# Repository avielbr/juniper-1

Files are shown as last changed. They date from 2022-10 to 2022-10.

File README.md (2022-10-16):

### Relevant datasheets:
- [ESP32-S2-WROOM](https://www.4project.co.il/documents/doc_664512_968259.pdf)
- [TMC6200-TA](https://www.mouser.co.il/datasheet/2/256/TMC6200_datasheet_Rev1_05-2529504.pdf) -- I also grabbed what I could from the picture in [this](https://community.simplefoc.com/t/esp32-s3-tmc6200-test-board/2418) thread discussing a board with the same MCU + gate driver.
- [NTMFS5C645NL](https://www.mouser.co.il/datasheet/2/308/NTMFS5C645NL_D-1814050.pdf) MOSFET
- [LDL1117S33R](https://www.mouser.co.il/datasheet/2/389/dm00366442-1799212.pdf) voltage regulator
- [TXU0104PWR](https://www.ti.com/lit/ds/symlink/txu0104.pdf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) level shifter

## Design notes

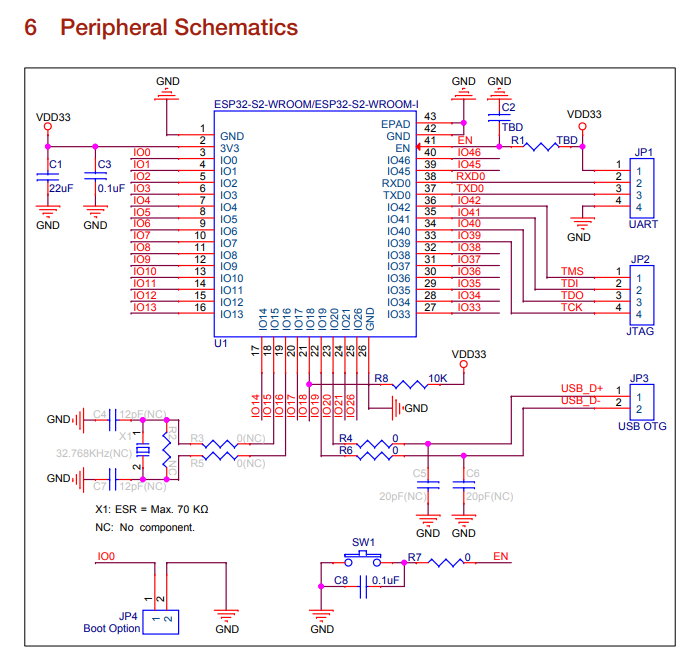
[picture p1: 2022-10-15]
kicad/parts/helper_schematics/ESP32_WROOM.png

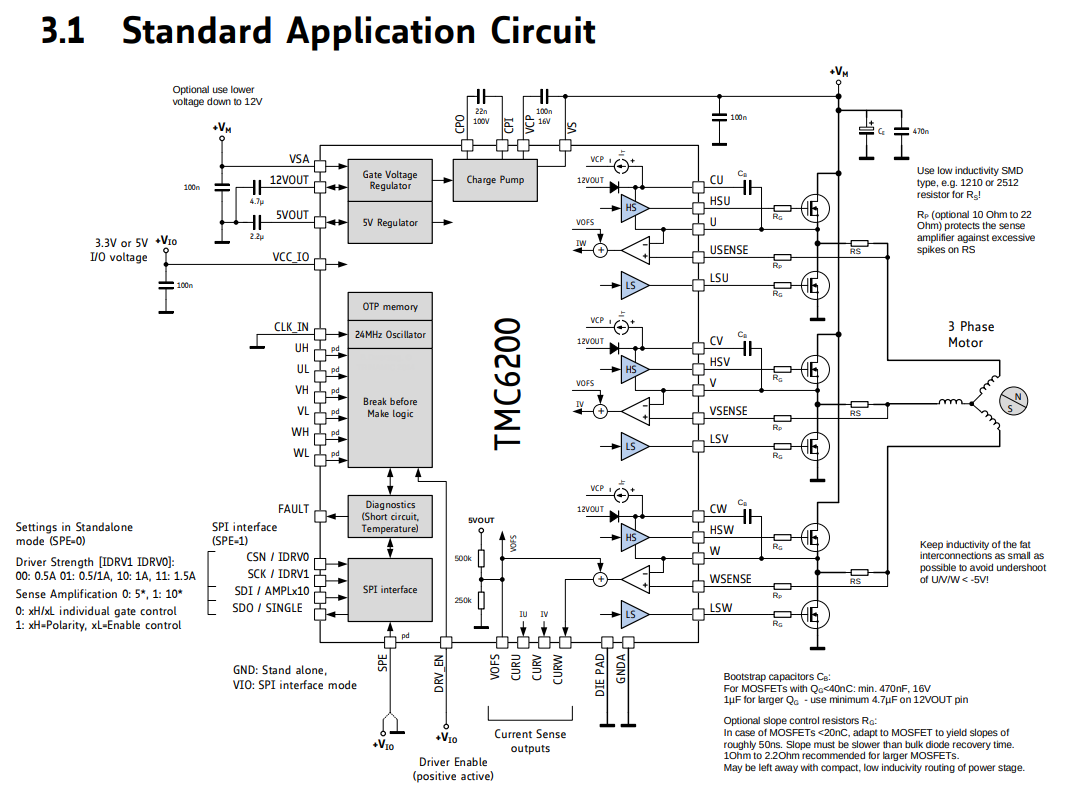
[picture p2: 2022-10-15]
kicad/parts/helper_schematics/gate_driver.png

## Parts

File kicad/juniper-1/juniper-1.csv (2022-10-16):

Source: | /home/avi/Documents/GitHub/juniper-1/kicad/juniper-1/juniper-1.kicad_sch
Date: | Sun 16 Oct 2022 02:57:48 PM IDT
Tool: | Eeschema 6.0.8-f2edbf62ab~116~ubuntu22.04.1
Generator: | /usr/share/kicad/plugins/bom_csv_grouped_by_value.py
Component Count: | 53
Individual Components:
Item | Qty | Reference(s) | Value | LibPart | Footprint | Datasheet | Arrow Part Number | Arrow Price/Stock | Availability | Description | Height | MANUFACTURER | MAXIMUM_PACKAGE_HEIGHT | MF | MP | Manufacturer_Name | Manufacturer_Part_Number | Mouser Part Number | Mouser Price/Stock | PARTREV | Package | Price | Purchase-URL | SNAPEDA_PN | STANDARD
 |  | C1 | 47uF | Device:C_Polarized | Capacitor_SMD:CP_Elec_10x10.5 | ~
 |  | C2 | 220uF | Device:C_Polarized | Capacitor_SMD:CP_Elec_10x10.5 | ~
 |  | C3 | 1500uF | Device:C_Polarized | Capacitor_SMD:CP_Elec_10x10.5 | ~
 |  | C4 | 2200uF | Device:C_Polarized | Capacitor_SMD:CP_Elec_10x10.5 | ~
 |  | C5 | 0.1uF | Device:C_Small | Capacitor_SMD:C_0402_1005Metric | ~
 |  | C6 | 22uF | Device:C_Small | Capacitor_SMD:C_0402_1005Metric | ~
 |  | C7 | 470nF | Device:C_Small | Capacitor_SMD:C_0402_1005Metric | ~
 |  | C8 | 100nF 16V | Device:C_Small | Capacitor_SMD:C_0402_1005Metric | ~
 |  | C9 | 22nF 100V | Device:C_Small | Capacitor_SMD:C_0402_1005Metric | ~
 |  | C10 | 100nF | Device:C_Small | Capacitor_SMD:C_0402_1005Metric | ~
 |  | C11 | 1uF | Device:C_Small | Capacitor_SMD:C_0402_1005Metric | ~
 |  | C12 | 470nF | Device:C_Small | Capacitor_SMD:C_0402_1005Metric | ~
 |  | C13 | 100nF | Device:C_Small | Capacitor_SMD:C_0402_1005Metric | ~
 |  | C14 | 470nF | Device:C_Small | Capacitor_SMD:C_0402_1005Metric | ~
 |  | C15 | 100nF | Device:C_Small | Capacitor_SMD:C_0402_1005Metric | ~
 |  | C16 | 0.1uF | Device:C_Small | Capacitor_SMD:C_0402_1005Metric | ~
 |  | C17 | 4.7uF | Device:C_Small | Capacitor_SMD:C_0402_1005Metric | ~
 |  | C18 | 2.2uF | Device:C_Small | Capacitor_SMD:C_0402_1005Metric | ~
 |  | C19 | 47uF | Device:C_Small | Capacitor_SMD:CP_Elec_6.3x7.7 | ~
 |  | C20 | 10uF | Device:C_Small | Capacitor_SMD:CP_Elec_6.3x7.7 | ~
 |  | J1 | BOOT_OPTION | Connector_Generic:Conn_01x02 | Connector_PinHeader_2.54mm:PinHeader_1x02_P2.54mm_Vertical | ~
 |  | J2 | UART | Connector_Generic:Conn_01x04 | Connector_PinHeader_2.54mm:PinHeader_1x04_P2.54mm_Vertical | ~
 |  | J3 | ENCODER | Connector_Generic:Conn_01x04 | Connector_PinSocket_2.54mm:PinSocket_1x04_P2.54mm_Vertical | ~
 |  | J4 | BATT_INPUT | Connector_Generic:Conn_01x02 | Connector_AMASS:AMASS_XT60-F_1x02_P7.20mm_Vertical | ~
 |  | J5 | 1714984 | 1714984:1714984 | 1714984 | https://www.phoenixcontact.com/online/portal/us/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 | 1714984 | https://www.arrow.com/en/products/1714984/phoenix-contact?region=nac |  | PCB terminal block, nominal current: 32 A, rated voltage (III/2): 1000 V, nominal cross section: 4 mm?, Number of potentials: 3, Number of rows: 1, Number of positions per row: 3, product range: MKDS 5, pitch: 9.52 mm, connection method: Screw connection with tension sleeve, mounting: Wave soldering, conductor/PCB connection direction: 0 ?, color: green, Pin layout: Linear pinning, Solder pin [P]: 5 mm, type of packaging: packed in cardboard. The article can be aligned to create different nos. of positions! | 21.7 |  |  |  |  | Phoenix Contact | 1714984 | 651-1714984 | https://www.mouser.co.uk/ProductDetail/Phoenix-Contact/1714984?qs=cyzODkzcbwBLTTPxtXl6gQ%3D%3D
 |  | Q1 | NTMFS5C645NL | NTMFS5C628NLT1G:NTMFS5C628NLT1G | TRANS_NTMFS5C628NLT1G |  |  |  |  |  |  | ON Semiconductor | 1.1 mm |  |  |  |  |  |  | 1 |  |  |  |  | Manufacturer recommendations
 |  | Q2 | NTMFS5C645NL | NTMFS5C628NLT1G:NTMFS5C628NLT1G | TRANS_NTMFS5C628NLT1G |  |  |  |  |  |  | ON Semiconductor | 1.1 mm |  |  |  |  |  |  | 1 |  |  |  |  | Manufacturer recommendations
 |  | Q3 | NTMFS5C645NL | NTMFS5C628NLT1G:NTMFS5C628NLT1G | TRANS_NTMFS5C628NLT1G |  |  |  |  |  |  | ON Semiconductor | 1.1 mm |  |  |  |  |  |  | 1 |  |  |  |  | Manufacturer recommendations
 |  | Q4 | NTMFS5C645NL | NTMFS5C628NLT1G:NTMFS5C628NLT1G | TRANS_NTMFS5C628NLT1G |  |  |  |  |  |  | ON Semiconductor | 1.1 mm |  |  |  |  |  |  | 1 |  |  |  |  | Manufacturer recommendations
 |  | Q5 | NTMFS5C645NL | NTMFS5C628NLT1G:NTMFS5C628NLT1G | TRANS_NTMFS5C628NLT1G |  |  |  |  |  |  | ON Semiconductor | 1.1 mm |  |  |  |  |  |  | 1 |  |  |  |  | Manufacturer recommendations
 |  | Q6 | NTMFS5C645NL | NTMFS5C628NLT1G:NTMFS5C628NLT1G | TRANS_NTMFS5C628NLT1G |  |  |  |  |  |  | ON Semiconductor | 1.1 mm |  |  |  |  |  |  | 1 |  |  |  |  | Manufacturer recommendations
 |  | R1 | 10K | Device:R_Small | Resistor_SMD:R_0603_1608Metric_Pad0.98x0.95mm_HandSolder | ~
 |  | R2 | 2 | Device:R_Small | Resistor_SMD:R_0603_1608Metric_Pad0.98x0.95mm_HandSolder | ~
 |  | R3 | 10K | Device:R_Small | Resistor_SMD:R_0603_1608Metric_Pad0.98x0.95mm_HandSolder | ~
 |  | R4 | 0.001 | Device:R_Small | Resistor_SMD:R_0603_1608Metric_Pad0.98x0.95mm_HandSolder | ~
 |  | R5 | 10 | Device:R_Small | Resistor_SMD:R_0603_1608Metric_Pad0.98x0.95mm_HandSolder | ~
 |  | R6 | 2 | Device:R_Small | Resistor_SMD:R_0603_1608Metric_Pad0.98x0.95mm_HandSolder | ~
 |  | R7 | 10K | Device:R_Small | Resistor_SMD:R_0603_1608Metric_Pad0.98x0.95mm_HandSolder | ~
 |  | R8 | 2 | Device:R_Small | Resistor_SMD:R_0603_1608Metric_Pad0.98x0.95mm_HandSolder | ~
 |  | R9 | 0.001 | Device:R_Small | Resistor_SMD:R_0603_1608Metric_Pad0.98x0.95mm_HandSolder | ~
 |  | R10 | 10 | Device:R_Small | Resistor_SMD:R_0603_1608Metric_Pad0.98x0.95mm_HandSolder | ~
 |  | R11 | 2 | Device:R_Small | Resistor_SMD:R_0603_1608Metric_Pad0.98x0.95mm_HandSolder | ~
 |  | R12 | 10K | Device:R_Small | Resistor_SMD:R_0603_1608Metric_Pad0.98x0.95mm_HandSolder | ~
 |  | R13 | 2 | Device:R_Small | Resistor_SMD:R_0603_1608Metric_Pad0.98x0.95mm_HandSolder | ~
 |  | R14 | 0.001 | Device:R_Small | Resistor_SMD:R_0603_1608Metric_Pad0.98x0.95mm_HandSolder | ~
 |  | R15 | 10 | Device:R_Small | Resistor_SMD:R_0603_1608Metric_Pad0.98x0.95mm_HandSolder | ~
 |  | R16 | 2 | Device:R_Small | Resistor_SMD:R_0603_1608Metric_Pad0.98x0.95mm_HandSolder | ~
 |  | R17 | 10K | Device:R_Small | Resistor_SMD:R_0603_1608Metric_Pad0.98x0.95mm_HandSolder | ~
 |  | SW1 | SW1 | Switch:SW_Push | Button_Switch_SMD:SW_Push_1P1T_NO_CK_PTS125Sx43PSMTR | ~
 |  | U1 | TMC6200-TA | TMC6200-TA:TMC6200-TA | eTQFP48_9x9_TRI
 |  | U2 | ESP32-S2-WROOM | ESP32-S2-WROOM:ESP32-S2-WROOM | XCVR_ESP32-S2-WROOM |  |  |  | In Stock | WiFi 802.11b/g/n Transceiver Module 2.4GHz Antenna Not Included, I-PEX Surface Mount |  |  |  | Espressif Systems | ESP32-S2-WROOM |  |  |  |  |  | NON STANDARD Espressif Systems | None | https://pricing.snapeda.com/search/part/ESP32-S2-WROOM/?ref=eda
 |  | U4 | TXB0102 | Logic_LevelTranslator:TXB0102DCT | Package_SO:TSSOP-8_3x3mm_P0.65mm | http://www.ti.com/lit/ds/symlink/txb0102.pdf
 |  | U5 | LDL1117S33R | LDL1117S30R:LDL1117S30R | SOT230P700X180-4N |  |  |  |  |  |  | STMicroelectronics | 1.8 mm |  |  |  |  |  |  | 7 |  |  |  | LDL1117S30R | IPC 7351B
Collated Components:
Item | Qty | Reference(s) | Value | LibPart | Footprint | Datasheet | Arrow Part Number | Arrow Price/Stock | Availability | Description | Height | MANUFACTURER | MAXIMUM_PACKAGE_HEIGHT | MF | MP | Manufacturer_Name | Manufacturer_Part_Number | Mouser Part Number | Mouser Price/Stock | PARTREV | Package | Price | Purchase-URL | SNAPEDA_PN | STANDARD
1 | 1 | C1 | 47uF | Device:C_Polarized | Capacitor_SMD:CP_Elec_10x10.5 | ~
2 | 1 | C2 | 220uF | Device:C_Polarized | Capacitor_SMD:CP_Elec_10x10.5 | ~
3 | 1 | C3 | 1500uF | Device:C_Polarized | Capacitor_SMD:CP_Elec_10x10.5 | ~
4 | 1 | C4 | 2200uF | Device:C_Polarized | Capacitor_SMD:CP_Elec_10x10.5 | ~
5 | 2 | C5, C16 | 0.1uF | Device:C_Small | Capacitor_SMD:C_0402_1005Metric | ~
6 | 1 | C6 | 22uF | Device:C_Small | Capacitor_SMD:C_0402_1005Metric | ~
7 | 3 | C7, C12, C14 | 470nF | Device:C_Small | Capacitor_SMD:C_0402_1005Metric | ~
8 | 1 | C8 | 100nF 16V | Device:C_Small | Capacitor_SMD:C_0402_1005Metric | ~
9 | 1 | C9 | 22nF 100V | Device:C_Small | Capacitor_SMD:C_0402_1005Metric | ~
10 | 3 | C10, C13, C15 | 100nF | Device:C_Small | Capacitor_SMD:C_0402_1005Metric | ~
11 | 1 | C11 | 1uF | Device:C_Small | Capacitor_SMD:C_0402_1005Metric | ~
12 | 1 | C17 | 4.7uF | Device:C_Small | Capacitor_SMD:C_0402_1005Metric | ~
13 | 1 | C18 | 2.2uF | Device:C_Small | Capacitor_SMD:C_0402_1005Metric | ~
14 | 1 | C19 | 47uF | Device:C_Small | Capacitor_SMD:CP_Elec_6.3x7.7 | ~
15 | 1 | C20 | 10uF | Device:C_Small | Capacitor_SMD:CP_Elec_6.3x7.7 | ~
16 | 1 | J1 | BOOT_OPTION | Connector_Generic:Conn_01x02 | Connector_PinHeader_2.54mm:PinHeader_1x02_P2.54mm_Vertical | ~
17 | 1 | J2 | UART | Connector_Generic:Conn_01x04 | Connector_PinHeader_2.54mm:PinHeader_1x04_P2.54mm_Vertical | ~
18 | 1 | J3 | ENCODER | Connector_Generic:Conn_01x04 | Connector_PinSocket_2.54mm:PinSocket_1x04_P2.54mm_Vertical | ~
19 | 1 | J4 | BATT_INPUT | Connector_Generic:Conn_01x02 | Connector_AMASS:AMASS_XT60-F_1x02_P7.20mm_Vertical | ~
20 | 1 | J5 | 1714984 | 1714984:1714984 | 1714984 | https://www.phoenixcontact.com/online/portal/us/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 | 1714984 | https://www.arrow.com/en/products/1714984/phoenix-contact?region=nac |  | PCB terminal block, nominal current: 32 A, rated voltage (III/2): 1000 V, nominal cross section: 4 mm?, Number of potentials: 3, Number of rows: 1, Number of positions per row: 3, product range: MKDS 5, pitch: 9.52 mm, connection method: Screw connection with tension sleeve, mounting: Wave soldering, conductor/PCB connection direction: 0 ?, color: green, Pin layout: Linear pinning, Solder pin [P]: 5 mm, type of packaging: packed in cardboard. The article can be aligned to create different nos. of positions! | 21.7 |  |  |  |  | Phoenix Contact | 1714984 | 651-1714984 | https://www.mouser.co.uk/ProductDetail/Phoenix-Contact/1714984?qs=cyzODkzcbwBLTTPxtXl6gQ%3D%3D
21 | 6 | Q1, Q2, Q3, Q4, Q5, Q6 | NTMFS5C645NL | NTMFS5C628NLT1G:NTMFS5C628NLT1G | TRANS_NTMFS5C628NLT1G |  |  |  |  |  |  | ON Semiconductor | 1.1 mm |  |  |  |  |  |  | 1 |  |  |  |  | Manufacturer recommendations
22 | 5 | R1, R3, R7, R12, R17 | 10K | Device:R_Small | Resistor_SMD:R_0603_1608Metric_Pad0.98x0.95mm_HandSolder | ~
23 | 6 | R2, R6, R8, R11, R13, R16 | 2 | Device:R_Small | Resistor_SMD:R_0603_1608Metric_Pad0.98x0.95mm_HandSolder | ~
24 | 3 | R4, R9, R14 | 0.001 | Device:R_Small | Resistor_SMD:R_0603_1608Metric_Pad0.98x0.95mm_HandSolder | ~
25 | 3 | R5, R10, R15 | 10 | Device:R_Small | Resistor_SMD:R_0603_1608Metric_Pad0.98x0.95mm_HandSolder | ~
26 | 1 | SW1 | SW1 | Switch:SW_Push | Button_Switch_SMD:SW_Push_1P1T_NO_CK_PTS125Sx43PSMTR | ~
27 | 1 | U1 | TMC6200-TA | TMC6200-TA:TMC6200-TA | eTQFP48_9x9_TRI
28 | 1 | U2 | ESP32-S2-WROOM | ESP32-S2-WROOM:ESP32-S2-WROOM | XCVR_ESP32-S2-WROOM |  |  |  | In Stock | WiFi 802.11b/g/n Transceiver Module 2.4GHz Antenna Not Included, I-PEX Surface Mount |  |  |  | Espressif Systems | ESP32-S2-WROOM |  |  |  |  |  | NON STANDARD Espressif Systems | None | https://pricing.snapeda.com/search/part/ESP32-S2-WROOM/?ref=eda
29 | 1 | U4 | TXB0102 | Logic_LevelTranslator:TXB0102DCT | Package_SO:TSSOP-8_3x3mm_P0.65mm | http://www.ti.com/lit/ds/symlink/txb0102.pdf
30 | 1 | U5 | LDL1117S33R | LDL1117S30R:LDL1117S30R | SOT230P700X180-4N |  |  |  |  |  |  | STMicroelectronics | 1.8 mm |  |  |  |  |  |  | 7 |  |  |  | LDL1117S30R | IPC 7351B

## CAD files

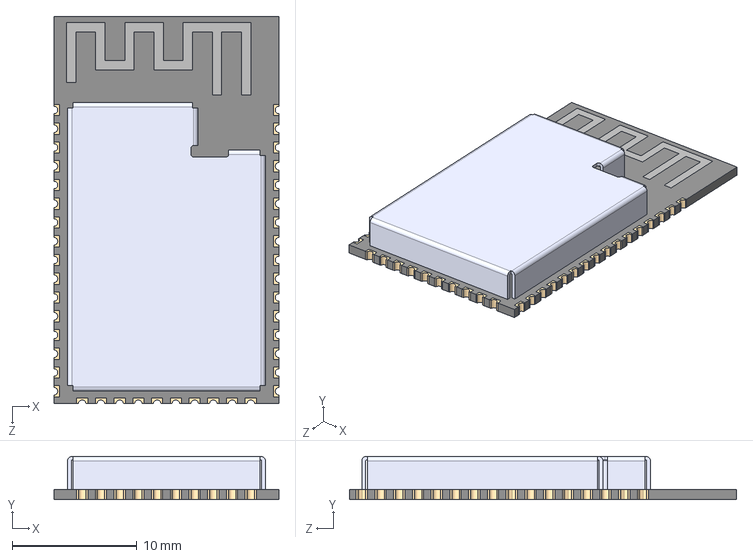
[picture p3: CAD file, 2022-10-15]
kicad/parts/ESP32-S2-WROOM/ESP32-S2-WROOM.step
18.0 x 3.45 x 31.0 mm

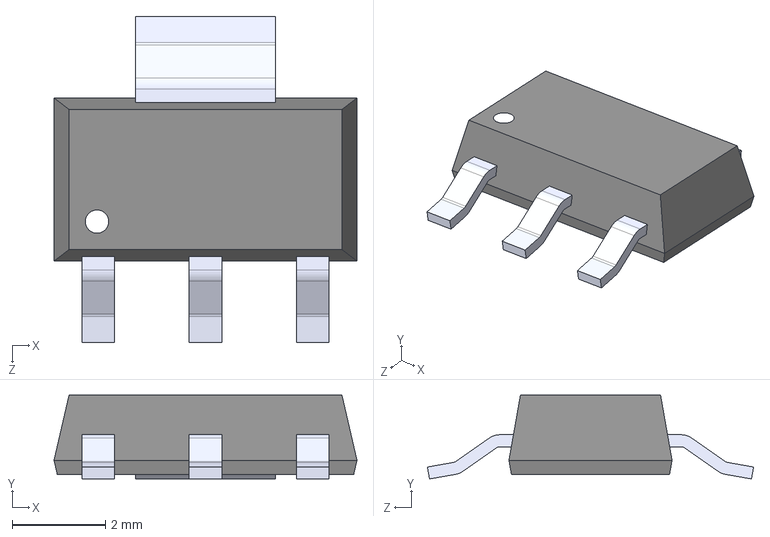
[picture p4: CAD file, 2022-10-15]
kicad/parts/LDL1117S30R/LDL1117S30R.step
6.50 x 1.80 x 7.00 mm

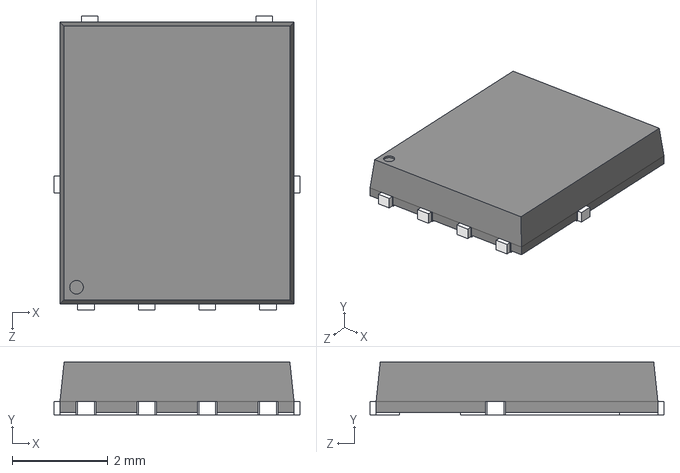
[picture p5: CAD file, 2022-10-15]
kicad/parts/NTMFS5C628NLT1G/NTMFS5C628NLT1G.step
5.15 x 1.10 x 6.15 mm

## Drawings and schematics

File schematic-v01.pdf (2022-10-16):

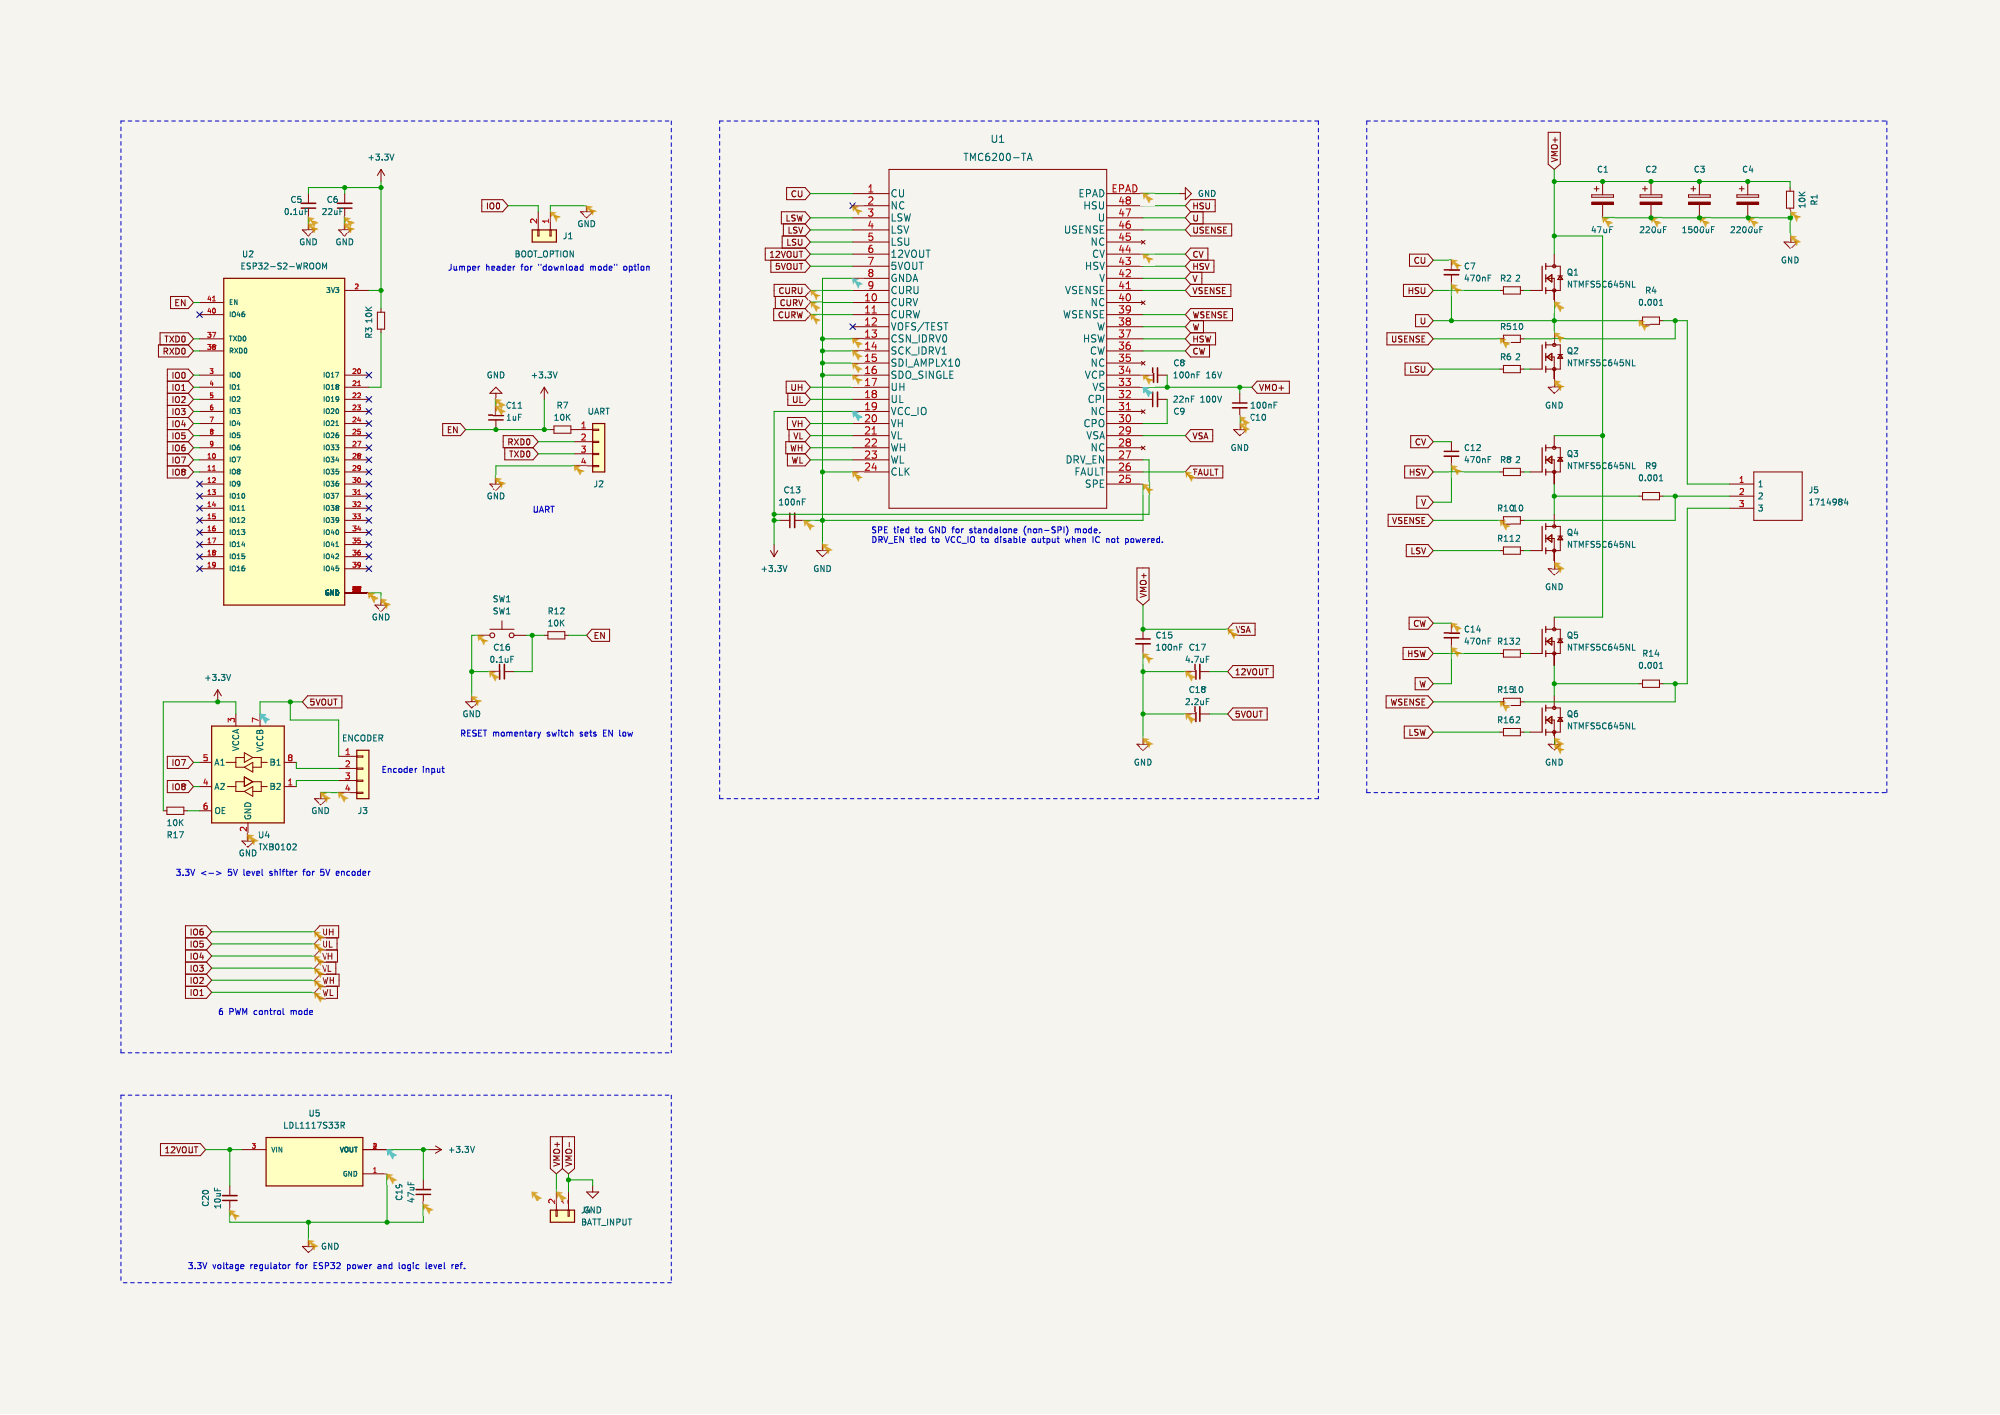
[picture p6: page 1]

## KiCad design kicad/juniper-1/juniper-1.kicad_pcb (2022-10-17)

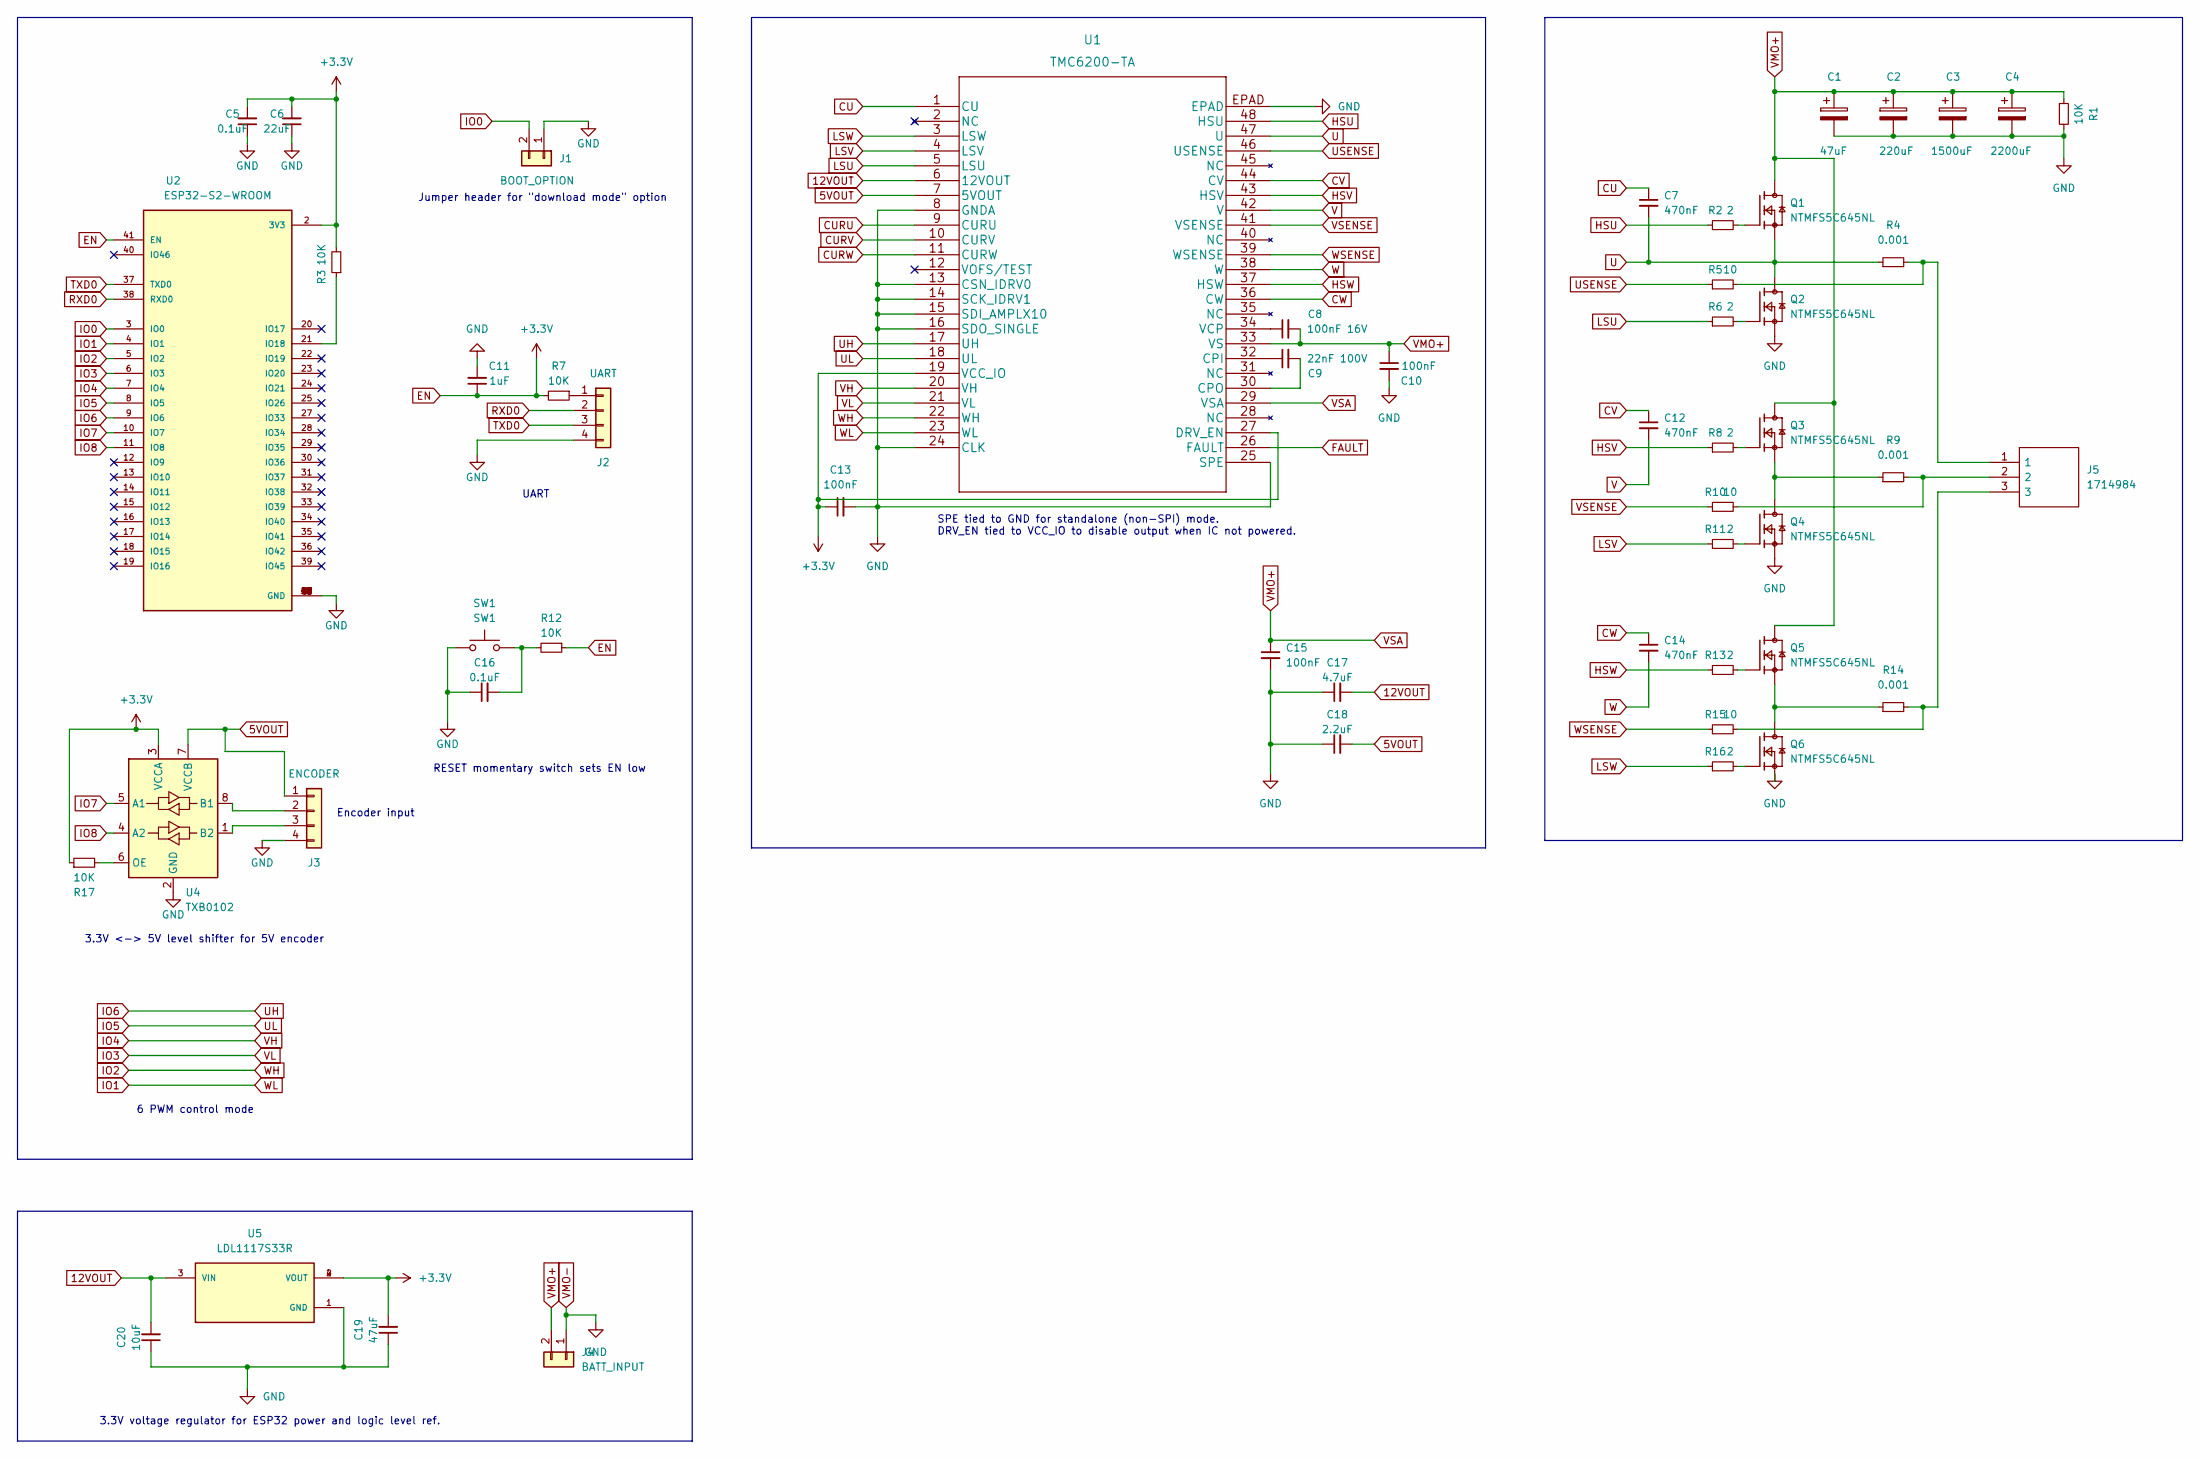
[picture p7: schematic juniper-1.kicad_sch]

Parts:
C1: 47uF; CP_Elec_10x10.5
C2: 220uF; CP_Elec_10x10.5
C3: 1500uF; CP_Elec_10x10.5
C4: 2200uF; CP_Elec_10x10.5
C5, C16: 0.1uF; C_0402_1005Metric
C6: 22uF; C_0402_1005Metric
C7, C12, C14: 470nF; C_0402_1005Metric
C8: 100nF 16V; C_0402_1005Metric
C9: 22nF 100V; C_0402_1005Metric
C10, C13, C15: 100nF; C_0402_1005Metric
C11: 1uF; C_0402_1005Metric
C17: 4.7uF; C_0402_1005Metric
C18: 2.2uF; C_0402_1005Metric
C19: 47uF; CP_Elec_6.3x7.7
C20: 10uF; CP_Elec_6.3x7.7
J1: BOOT_OPTION; PinHeader_1x02_P2.54mm_Vertical
J2: UART; PinHeader_1x04_P2.54mm_Vertical
J3: ENCODER; PinSocket_1x04_P2.54mm_Vertical
J4: BATT_INPUT; AMASS_XT60-F_1x02_P7.20mm_Vertical
J5: 1714984; Manufacturer_Part_Number 1714984; Mouser Part Number 651-1714984
Q1, Q2, Q3, Q4, Q5, Q6: NTMFS5C645NL; TRANS_NTMFS5C628NLT1G; PARTREV 1
R1, R3, R7, R12, R17: 10K; R_0603_1608Metric_Pad0.98x0.95mm_HandSolder
R2, R6, R8, R11, R13, R16: 2; R_0603_1608Metric_Pad0.98x0.95mm_HandSolder
R4, R9, R14: 0.001; R_0603_1608Metric_Pad0.98x0.95mm_HandSolder
R5, R10, R15: 10; R_0603_1608Metric_Pad0.98x0.95mm_HandSolder
SW1: SW1; SW_Push_1P1T_NO_CK_PTS125Sx43PSMTR
U1: TMC6200-TA
U2: ESP32-S2-WROOM; XCVR_ESP32-S2-WROOM
U4: TXB0102; TSSOP-8_3x3mm_P0.65mm
U5: LDL1117S33R; SOT230P700X180-4N; PARTREV 7

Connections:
5VOUT: C18.2, J3.1, U1.7 (5VOUT), U4.7 (VCCB)
12VOUT: C17.2, C20.2, U1.6 (12VOUT), U5.3 (VIN)
CU: C7.1, U1.1 (CU)
CURU: U1.9 (CURU)
CURV: U1.10 (CURV)
CURW: U1.11 (CURW)
CV: C12.1, U1.44 (CV)
CW: C14.1, U1.36 (CW)
EN: C5.2, C6.2, C11.1, C13.1, C19.2, R3.2, R7.2, R12.1, R17.1, U1.19 (VCC_IO), U1.27 (DRV_EN), U2.2 (3V3), U2.41 (EN), U4.3 (VCCA), U5.2 (VOUT), U5.4 (VOUT)
FAULT: U1.26 (FAULT)
HSU: R2.1, U1.48 (HSU)
HSV: R8.1, U1.43 (HSV)
HSW: R13.1, U1.37 (HSW)
IO0: J1.2, U2.3 (IO0)
IO1: U1.23 (WL), U2.4 (IO1)
IO2: U1.22 (WH), U2.5 (IO2)
IO3: U1.21 (VL), U2.6 (IO3)
IO4: U1.20 (VH), U2.7 (IO4)
IO5: U1.18 (UL), U2.8 (IO5)
IO6: U1.17 (UH), U2.9 (IO6)
IO7: U2.10 (IO7), U4.5 (A1)
IO8: U2.11 (IO8), U4.4 (A2)
LSU: R6.1, U1.5 (LSU)
LSV: R11.1, U1.4 (LSV)
LSW: R16.1, U1.3 (LSW)
unnamed: C8.1, U1.34 (VCP)
unnamed: C9.1, U1.32 (CPI)
unnamed: C9.2, U1.30 (CPO)
unnamed: C16.2, R12.2, SW1.2
unnamed: J2.1, R7.1
unnamed: J3.2, U4.8 (B1)
unnamed: J3.3, U4.1 (B2)
unnamed: Q1.4, R2.2
unnamed: Q2.4, R6.2
unnamed: Q3.1, Q3.2, Q3.3, Q4.5, R9.1
unnamed: Q3.4, R8.2
unnamed: Q4.4, R11.2
unnamed: Q5.1, Q5.2, Q5.3, Q6.5, R14.1
unnamed: Q5.4, R13.2
unnamed: Q6.4, R16.2
unnamed: J5.1, R4.2, R5.2
unnamed: J5.2, R9.2, R10.2
unnamed: J5.3, R14.2, R15.2
unnamed: R3.1, U2.21 (IO18)
unnamed: R17.2, U4.6 (OE)
RXD0: J2.2, U2.38 (RXD0)
TXD0: J2.3, U2.37 (TXD0)
U: C7.2, Q1.1, Q1.2, Q1.3, Q2.5, R4.1, U1.47 (U)
USENSE: R5.1, U1.46 (USENSE)
V: C12.2, U1.42 (V)
VMO+: C1.1, C2.1, C3.1, C4.1, C8.2, C10.1, C15.1, J4.2, Q1.5, Q3.5, Q5.5, R1.1, U1.29 (VSA), U1.33 (VS)
VMO-: C1.2, C2.2, C3.2, C4.2, C5.1, C6.1, C10.2, C11.2, C13.2, C15.2, C16.1, C17.1, C18.1, C19.1, C20.1, J1.1, J2.4, J3.4, J4.1, Q2.1, Q2.2, Q2.3, Q4.1, Q4.2, Q4.3, Q6.1, Q6.2, Q6.3, R1.2, SW1.1, U1.8 (GNDA), U1.13 (CSN_IDRV0), U1.14 (SCK_IDRV1), U1.15 (SDI_AMPLX10), U1.16 (SDO_SINGLE), U1.24 (CLK), U1.25 (SPE), U1.EPAD, U2.1 (GND), U2.26 (GND), U2.42 (GND), U2.43 (GND), U2.44 (GND), U2.45 (GND), U2.46 (GND), U2.47 (GND), U2.48 (GND), U2.49 (GND), U2.50 (GND), U2.51 (GND), U4.2 (GND), U5.1 (GND)
VSENSE: R10.1, U1.41 (VSENSE)
W: C14.2, U1.38 (W)
WSENSE: R15.1, U1.39 (WSENSE)

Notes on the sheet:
UART
6 PWM control mode
3.3V voltage regulator for ESP32 power and logic level ref.
Jumper header for "download mode" option
RESET momentary switch sets EN low
3.3V <-> 5V level shifter for 5V encoder
SPE tied to GND for standalone (non-SPI) mode. DRV_EN tied to VCC_IO to disable output when IC not powered.
Encoder input

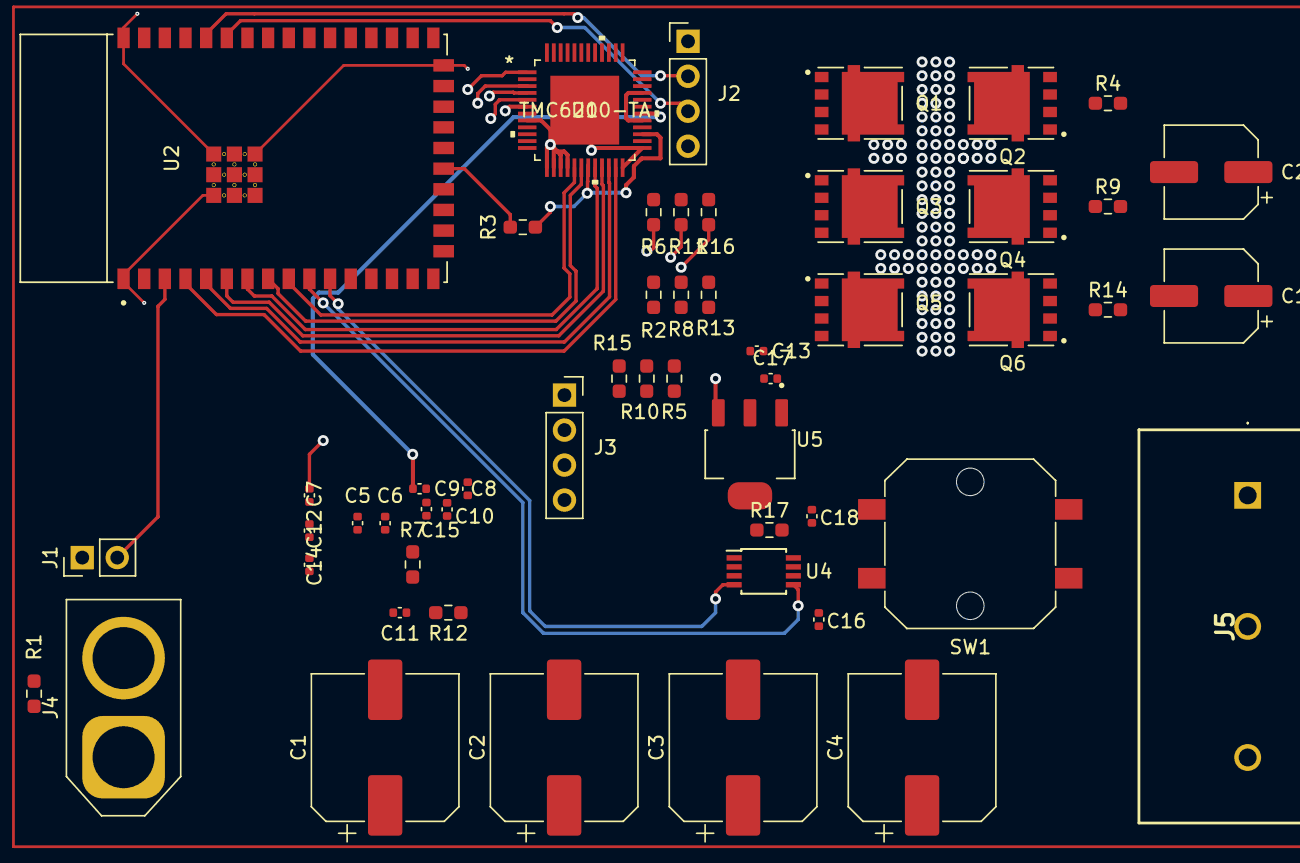
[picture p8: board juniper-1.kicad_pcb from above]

Board: 4 copper layers, 53 parts (0 on the bottom side), 51 nets.

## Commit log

2022-10-15 Everything before assigning ESP32 pins
    [NTMFS5C628NLT1G.step, juniper-1.kicad_pcb, juniper-1.kicad_sch]
2022-10-15 added power supply for ESP32, haven't yet finished assigning esp32 pins
    [LDL1117S30R.step, juniper-1.kicad_sch]
2022-10-15 fixed esp32 symbol, nearly finished assigning pins for MCU
    [ESP32-S2-WROOM.step, juniper-1.kicad_sch]
2022-10-16 Fixed voltage regulator, organized, added text, added encoder input
    [juniper-1.kicad_sch]
2022-10-16 assigned footprints, just about to start editing board!
    [juniper-1.csv]
2022-10-16 added schematic, started routing
    [juniper-1.kicad_pcb, juniper-1.kicad_sch]
2022-10-17 restarting the pcb layout...
2022-10-17 made lots of progress with rerouting the PCB
    [juniper-1.kicad_pcb]
2022-10-24 removed current sense for now...
    [juniper-1.kicad_sch]

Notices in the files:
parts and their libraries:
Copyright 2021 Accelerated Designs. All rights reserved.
